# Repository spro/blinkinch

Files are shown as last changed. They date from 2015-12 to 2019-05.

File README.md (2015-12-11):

# blinkinch

Square inch clone of the blink(1) indicator light with ATTiny85 and V-USB.

Created to participate in the [Square Inch Project](https://hackaday.io/project/7813-the-square-inch-project). The design goal was to make something somewhat useful (a programmable indicator light) that is very easy to reproduce (with minimal, common, through-hole parts).

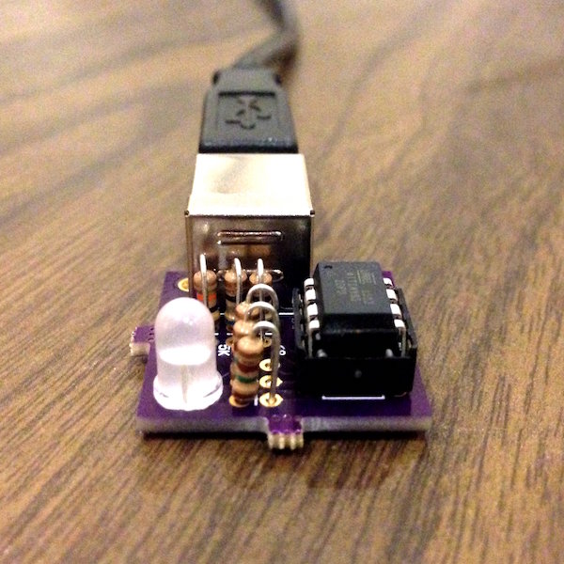
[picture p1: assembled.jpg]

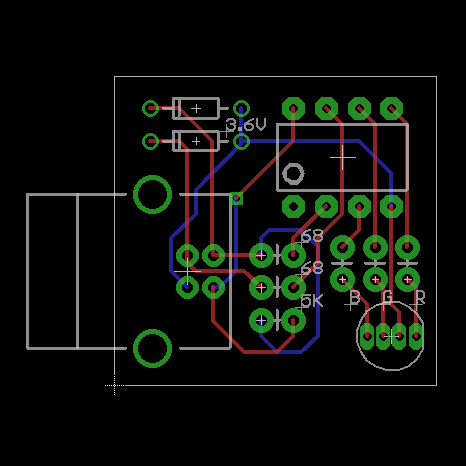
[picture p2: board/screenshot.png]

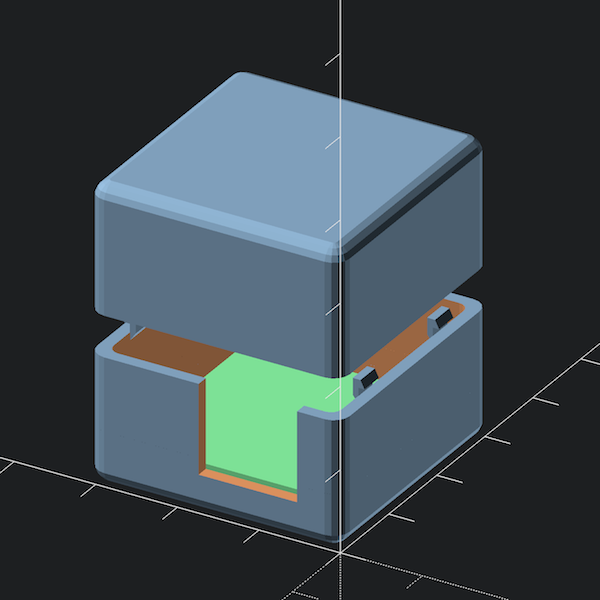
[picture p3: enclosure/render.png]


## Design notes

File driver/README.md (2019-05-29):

# blink(inch) Python USB driver

Requires [pyusb](https://github.com/walac/pyusb)

# Usage

Use with the command line client:

```bash
python set_rgb.py 1 0 1
```

Or import into a script:

```python
from device import set_rgb
set_rgb(1, 0, 0)
```

# API

The API consists of a single method: `set_rgb`

`set_rgb(int r, int g, int b)`

`r` `g` `b` values are `0` or `1` until fading RGB has been implemented.

# Permissions

If you see `usb.core.USBError: [Errno 13] Access denied (insufficient permissions)`, give yourself the correct permissions by creating a udev rule.

Create a group for the device and add yourself to it:

```bash
sudo groupadd blinkinch
sudo gpasswd -a myself blinkinch
```

Create a udev rule to give the group full permission to the device:

```bash
/lib/udev/rules.d/50-blinkinch.rules:
SUBSYSTEMS=="usb", ATTRS{idVendor}=="7372", ATTRS{idProduct}=="6b74", MODE="666", GROUP="blinkinch"
```

Unplug it, then re-trigger the udev rules:

```bash
sudo udevadm trigger
```

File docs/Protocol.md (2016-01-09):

# Protocol

The protocol defines a single host->device control message for setting the color of the blink(inch): 

`SET_RGB(r g b)`

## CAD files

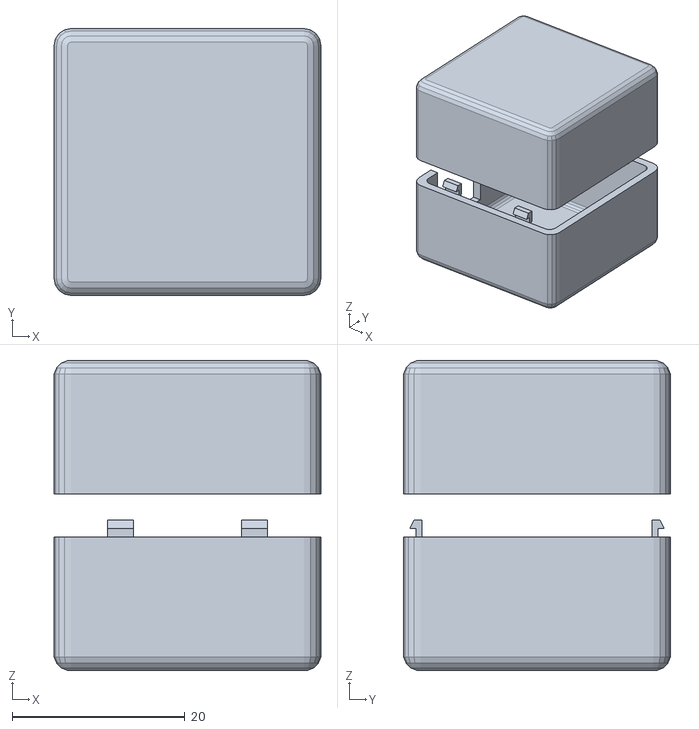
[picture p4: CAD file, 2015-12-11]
enclosure/blinkinch.stl
30.9 x 30.9 x 35.9

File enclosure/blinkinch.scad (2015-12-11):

wall = 1.5; // Decent thickness
inch = 25.4;
corner_r = 2;
outr = 2;
inr = 1.3;
epsilon = 0.001;

notch_w = 3;
notch_neck_h = 1;
notch_head_h = 1;
notch_t = 0.7;
notch_in = wall/2;

usb_h = 10.9;
usb_w = 12.05;

pcb_t = 1.6;
lead_t = 1.5;

board_offset = wall+corner_r/2;
board_w = in2mm(0.98);
board_l = in2mm(0.94);

$fn=16;

h = wall + pcb_t + lead_t + usb_h;
l = h * 2;
w = h * 2;

function mm2in(mm) = mm / inch;
function in2mm(in) = in * inch;

module round_cube(l, w, h, r=2) {
    hull() {
        for(x=[0+r, l-r]) {
            for(y=[0+r, w-r]) {
                for(z=[0+r, h-r]) {
                    translate([x, y, z])
                    sphere(r);
                }
            }
        }
    }
}

// Notches
module notch() {
    linear_extrude(height=notch_w) {
        // Neck
        polygon([
            [0, 0], [notch_t,-1], [notch_t,notch_neck_h], [0, notch_neck_h]
        ], [
            [0, 1, 2, 3]
        ]);
        translate([0, notch_neck_h, 0])
        // Head
        polygon([
            [0, 0], [notch_t+notch_in,0], [notch_t+notch_in/3,notch_head_h], [0, notch_head_h]
        ], [
            [0, 1, 2, 3]
        ]);
    }
}

module bottom_notches() {
    for(x=[l/4, l*3/4]) {
        translate([x+notch_w/2, wall+notch_t, h])
        rotate([90, 00, 270])
        notch();

        translate([x-notch_w/2, w-wall-notch_t, h])
        rotate([90, 00, 90])
        notch();
    }
}

module bottom() {
    difference() {
        // Full shell
        intersection() {
            difference() {
                round_cube(l, w, h*2, r=outr);
                translate([wall, wall, wall])
                round_cube(l-2*wall, w-2*wall, (h-wall)*2, r=inr);
            }
            // Intersect with bottom half
            cube([l, w, h]);
        }

        // USB Plug hole
        hole_z = wall + 3.10;
        translate([-1, board_offset + in2mm(0.35) - usb_w/2, hole_z])
        cube([usb_w, usb_w, usb_h+epsilon]);

        // Air holes
        /* for (ai=[2:9]) { */
        /*     translate([l-2*ai, -epsilon, wall]) */
        /*     cube([1, w+2*epsilon, h-2*wall]); */
        /* } */
    }

    bottom_notches();
}

module top() {
    translate([0, 0, 5]) {
        // Main shell
        difference() {
            intersection() {
                difference() {
                    round_cube(l, w, h*2, r=outr);
                    translate([wall, wall, wall])
                    round_cube(l-2*wall, w-2*wall, (h-wall)*2, r=inr);
                }
                // Top half
                translate([0, 0, h])
                cube([l, w, h]);
            }
            
            // Notch holes
            translate([l/4-notch_w/2, wall-notch_in, h+notch_neck_h])
            cube([notch_w, w-2*notch_in, notch_head_h]);
            translate([l*3/4-notch_w/2, wall-notch_in, h+notch_neck_h])
            cube([notch_w, w-2*notch_in, notch_head_h]);

            // Maia logo
            /* logo_w = w * 2/3; */
            /* translate([(w-logo_w)/2, (w-logo_w)/2, h*2-(wall-0.7)]) */
            /* linear_extrude(height=1+epsilon) resize([logo_w, logo_w]) import("/Users/sean/Desktop/20151116/lohgo.dxf"); */
        }
    }
}

module board() {
    translate([board_offset, board_offset, wall + lead_t])
    color([0.5, 0.9, 0.6])
    cube([board_w, board_l, pcb_t]);
}

bottom();
*board();
top();

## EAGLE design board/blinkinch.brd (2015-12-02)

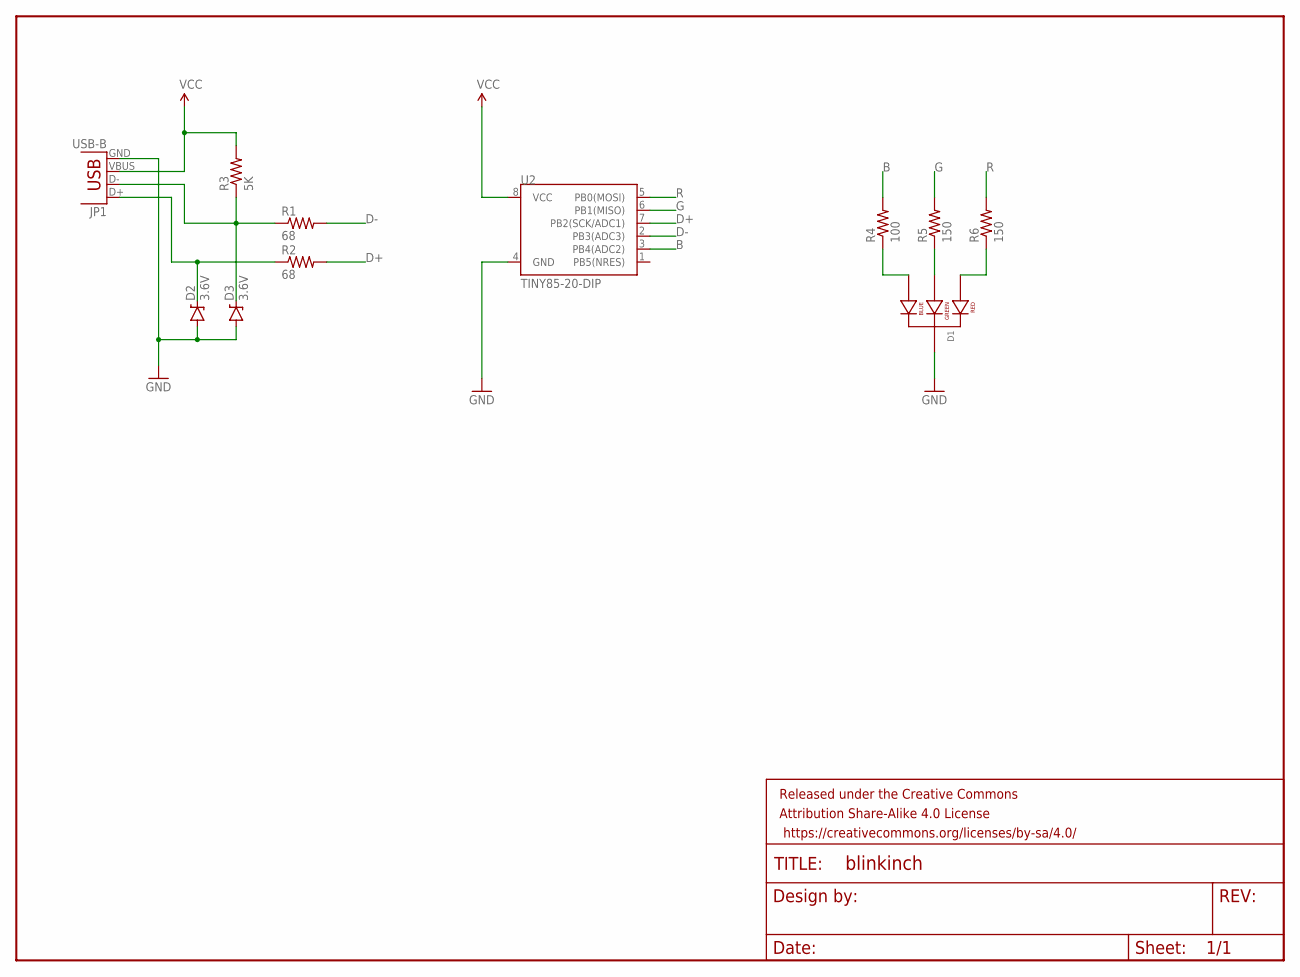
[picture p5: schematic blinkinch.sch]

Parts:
D1: LED-RGB-CC-THRUCLEAR; LED-RGB-THRU
D2, D3: 3.6V; DIODE-ZENER
FRAME1: FRAME-LETTER; CREATIVE_COMMONS
JP1: USB-B; USB-B-PTH
R1, R2: 68; AXIAL-0.1
R3: 5K; AXIAL-0.1
R4: 100; AXIAL-0.1
R5, R6: 150; AXIAL-0.1
U2: TINY85-20-DIP; DIP08

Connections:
B: R4.P$2 (2), U2.3 (PB4(ADC2))
D+: R2.P$2 (2), U2.7 (PB2(SCK/ADC1))
D-: R1.P$2 (2), U2.2 (PB3(ADC3))
G: R5.P$2 (2), U2.6 (PB1(MISO))
GND: D1.2 (CATHODE), D2.P$2 (A), D3.P$2 (A), JP1.GND, U2.4 (GND)
unnamed: D1.4 (BLUE_CATHODE), R4.P$1 (1)
unnamed: D1.3 (GREEN_CATHODE), R5.P$1 (1)
unnamed: D1.1 (RED_CATHODE), R6.P$1 (1)
unnamed: D3.P$1 (C), JP1.D-, R1.P$1 (1), R3.P$1 (1)
unnamed: D2.P$1 (C), JP1.D+, R2.P$1 (1)
R: R6.P$2 (2), U2.5 (PB0(MOSI))
VCC: JP1.VBUS, R3.P$2 (2), U2.8 (VCC)

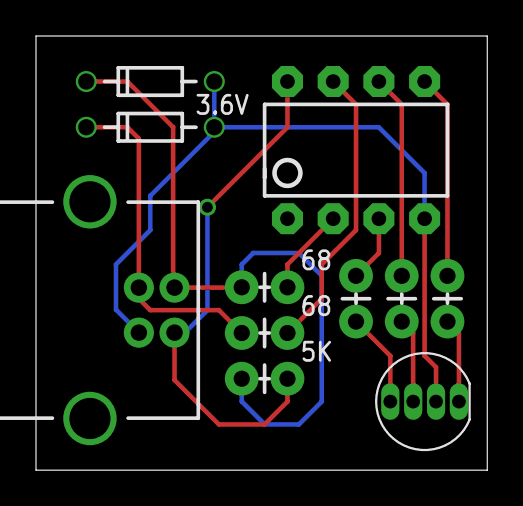
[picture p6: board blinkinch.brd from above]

Board: 2 copper layers, 25.1 x 24.1 mm, 12 parts (0 on the bottom side), 12 nets.

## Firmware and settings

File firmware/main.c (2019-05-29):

#include <avr/io.h>
#include <avr/interrupt.h>
#include <avr/wdt.h>
#include <avr/eeprom.h>
#include <avr/pgmspace.h>
#include <util/delay.h>

#include "usbdrv.h"

uchar n_modes = 8;
uchar mode = 0;
uchar current = 0;
uchar max_value = 16;

// USB Setup
// -----------------------------------------------------------------------------

#define USB_SET_RGB 0

static uchar reportBuf[16];
static uchar replyBuf[16] = "Hello there";

uchar color_r = 0;
uchar color_g = 0;
uchar color_b = 0;

uchar usbFunctionSetup(uchar data[8]) {
    usbRequest_t *rq = (void *)data;
    int val;

    switch(rq->bRequest) {
        case USB_SET_RGB:
            // TODO: Get mode from data
            val = rq->wValue.bytes[0];
            color_r = (val & (1 << 0)) >> 0;
            color_g = (val & (1 << 1)) >> 1;
            color_b = (val & (1 << 2)) >> 2;
            show_color();
            return 0;
        default:
            return USB_NO_MSG;
    }

	return 0;
}

uchar usbFunctionRead(uchar *data, uchar len) {
    data[0] = 0xf3;
    return len;
}

void usbFunctionWriteOut(uchar * data, uchar len) {

}

void usbEventResetReady(void) {
    setCalibration();
}

#define BLINK_MS 100
#define R_PIN 0
#define G_PIN 1
#define B_PIN 4

void show_color() {
    if (color_r)
        PORTB |= (1 << R_PIN);
    else
        PORTB &= ~(1 << R_PIN);
    if (color_g)
        PORTB |= (1 << G_PIN);
    else
        PORTB &= ~(1 << G_PIN);
    if (color_b)
        PORTB |= (1 << B_PIN);
    else
        PORTB &= ~(1 << B_PIN);
}

void blink() {
    PORTB |= (1 << R_PIN);
    _delay_ms(BLINK_MS);
    PORTB &= ~(1 << R_PIN);
    _delay_ms(BLINK_MS);
}

uint32_t recovering = 0;
#define DEBOUNCE   10000
int next = 0;

int main() {
    wdt_disable();
	
    readCalibration();

	DDRB |= (1 << R_PIN) | (1 << B_PIN) | (1 << G_PIN);
    blink();

    // Reconnection cycle
    usbDeviceDisconnect();
    uchar i;
    for(i=0;i<60;i++){  /* 500 ms disconnect */
        wdt_reset();
        _delay_ms(15);
    }
    usbDeviceConnect();

    wdt_enable(WDTO_1S);
    usbInit();

    //sei();

    blink();
    blink();

    uchar keydown = 0;

    int trying = 0;

    while(1) {
        wdt_reset(); // keep the watchdog happy
        usbPoll();
    }

    return 0;
}

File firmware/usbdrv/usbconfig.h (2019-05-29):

/* Name: usbconfig.h
 * Project: AVR USB driver
 * Author: Christian Starkjohann
 * Creation Date: 2007-06-23
 * Tabsize: 4
 * Copyright: (c) 2007 by OBJECTIVE DEVELOPMENT Software GmbH
 * License: GNU GPL v2 (see License.txt) or proprietary (CommercialLicense.txt)
 * This Revision: $Id$
 */

#ifndef __usbconfig_h_included__
#define __usbconfig_h_included__

/* ---------------------------- Hardware Config ---------------------------- */

#define USB_CFG_IOPORTNAME      B
/* This is the port where the USB bus is connected. When you configure it to
 * "B", the registers PORTB, PINB and DDRB will be used.
 */
#define USB_CFG_DMINUS_BIT      3
/* This is the bit number in USB_CFG_IOPORT where the USB D- line is connected.
 * This may be any bit in the port.
 */
#define USB_CFG_DPLUS_BIT       2
/* This is the bit number in USB_CFG_IOPORT where the USB D+ line is connected.
 * This may be any bit in the port. Please note that D+ must also be connected
 * to interrupt pin INT0!
 */
#define USB_CFG_CLOCK_KHZ       (F_CPU/1000)
/* Clock rate of the AVR in MHz. Legal values are 12000, 16000 or 16500.
 * The 16.5 MHz version of the code requires no crystal, it tolerates +/- 1%
 * deviation from the nominal frequency. All other rates require a precision
 * of 2000 ppm and thus a crystal!
 * Default if not specified: 12 MHz
 */

/* ----------------------- Optional Hardware Config ------------------------ */

/* #define USB_CFG_PULLUP_IOPORTNAME   D */
/* If you connect the 1.5k pullup resistor from D- to a port pin instead of
 * V+, you can connect and disconnect the device from firmware by calling
 * the macros usbDeviceConnect() and usbDeviceDisconnect() (see usbdrv.h).
 * This constant defines the port on which the pullup resistor is connected.
 */
/* #define USB_CFG_PULLUP_BIT          4 */
/* This constant defines the bit number in USB_CFG_PULLUP_IOPORT (defined
 * above) where the 1.5k pullup resistor is connected. See description
 * above for details.
 */

/* --------------------------- Functional Range ---------------------------- */

#define USB_CFG_HAVE_INTRIN_ENDPOINT    1
/* Define this to 1 if you want to compile a version with two endpoints: The
 * default control endpoint 0 and an interrupt-in endpoint 1.
 */
#define USB_CFG_HAVE_INTRIN_ENDPOINT3   0
/* Define this to 1 if you want to compile a version with three endpoints: The
 * default control endpoint 0, an interrupt-in endpoint 1 and an interrupt-in
 * endpoint 3. You must also enable endpoint 1 above.
 */
#define USB_CFG_IMPLEMENT_HALT          0
/* Define this to 1 if you also want to implement the ENDPOINT_HALT feature
 * for endpoint 1 (interrupt endpoint). Although you may not need this feature,
 * it is required by the standard. We have made it a config option because it
 * bloats the code considerably.
 */
#define USB_CFG_INTR_POLL_INTERVAL      10
/* If you compile a version with endpoint 1 (interrupt-in), this is the poll
 * interval. The value is in milliseconds and must not be less than 10 ms for
 * low speed devices.
 */
#define USB_CFG_IS_SELF_POWERED         0
/* Define this to 1 if the device has its own power supply. Set it to 0 if the
 * device is powered from the USB bus.
 */
#define USB_CFG_MAX_BUS_POWER           50
/* Set this variable to the maximum USB bus power consumption of your device.
 * The value is in milliamperes. [It will be divided by two since USB
 * communicates power requirements in units of 2 mA.]
 */
#define USB_CFG_IMPLEMENT_FN_WRITE      0
/* Set this to 1 if you want usbFunctionWrite() to be called for control-out
 * transfers. Set it to 0 if you don't need it and want to save a couple of
 * bytes.
 */
#define USB_CFG_IMPLEMENT_FN_READ       0
/* Set this to 1 if you need to send control replies which are generated
 * "on the fly" when usbFunctionRead() is called. If you only want to send
 * data from a static buffer, set it to 0 and return the data from
 * usbFunctionSetup(). This saves a couple of bytes.
 */
#define USB_CFG_IMPLEMENT_FN_WRITEOUT   0
/* Define this to 1 if you want to use interrupt-out (or bulk out) endpoint 1.
 * You must implement the function usbFunctionWriteOut() which receives all
 * interrupt/bulk data sent to endpoint 1.
 */
#define USB_CFG_HAVE_FLOWCONTROL        0
/* Define this to 1 if you want flowcontrol over USB data. See the definition
 * of the macros usbDisableAllRequests() and usbEnableAllRequests() in
 * usbdrv.h.
 */
#ifndef __ASSEMBLER__
extern void usbEventResetReady(void);
#endif
#define USB_RESET_HOOK(isReset)             if(!isReset){usbEventResetReady();} 
/* This macro is a hook if you need to know when an USB RESET occurs. It has
 * one parameter which distinguishes between the start of RESET state and its
 * end.
 */
#define USB_CFG_HAVE_MEASURE_FRAME_LENGTH   1
/* define this macro to 1 if you want the function usbMeasureFrameLength()
 * compiled in. This function can be used to calibrate the AVR's RC oscillator.
 */
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

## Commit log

2015-12-11 openscad enclosure
    [blinkinch.scad, blinkinch.stl]
2016-01-10 add python driver

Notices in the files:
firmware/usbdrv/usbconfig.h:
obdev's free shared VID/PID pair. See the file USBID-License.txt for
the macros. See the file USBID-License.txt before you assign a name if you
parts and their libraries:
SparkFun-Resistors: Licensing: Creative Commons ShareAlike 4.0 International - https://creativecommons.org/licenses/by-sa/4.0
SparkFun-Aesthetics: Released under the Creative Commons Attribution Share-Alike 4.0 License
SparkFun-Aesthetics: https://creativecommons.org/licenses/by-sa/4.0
